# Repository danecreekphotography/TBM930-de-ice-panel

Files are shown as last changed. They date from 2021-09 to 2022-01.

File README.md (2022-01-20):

# TBM930 de-ice panel PCB

This PCB implements a TBM930 de-ice panel for use with Microsoft Flight Simulator
2020 and [MobiFlight](http://www.mobiflight.com/).



## KiBot automation

This repo also demonstrates using KiBot for full CI/CD of KiCad projects. Every pull request gets ERC/DRC checks.
Publishing a GitHub release triggers generation of a suite of PCB documentation, interactive BOM, and submission
files for JLCPCB (including pick-and-place files) and PCBWay. The GitHub release version is inserted into the
generated documentation and gerber files as well. A manually triggered workflow to generate documentation is also
included.

Want to use KiBot GitHub automation with your own project? Check out my [GitHub repository template](https://github.com/neilenns/KiBot-CICD-Template/) for KiCad CI/CD to get started!

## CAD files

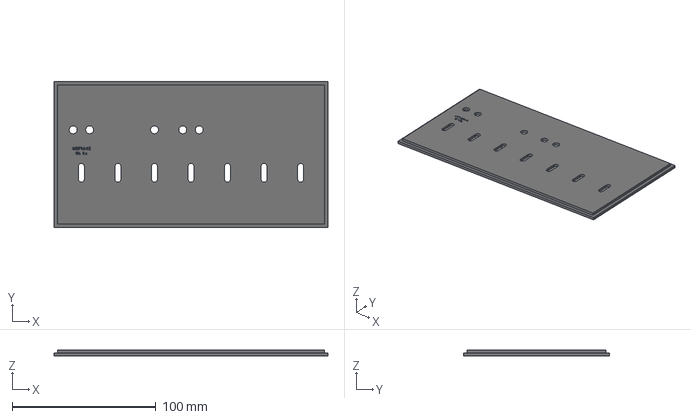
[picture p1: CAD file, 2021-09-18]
3d models/De-ice panel.step
190.5 x 101.6 x 4.00 mm

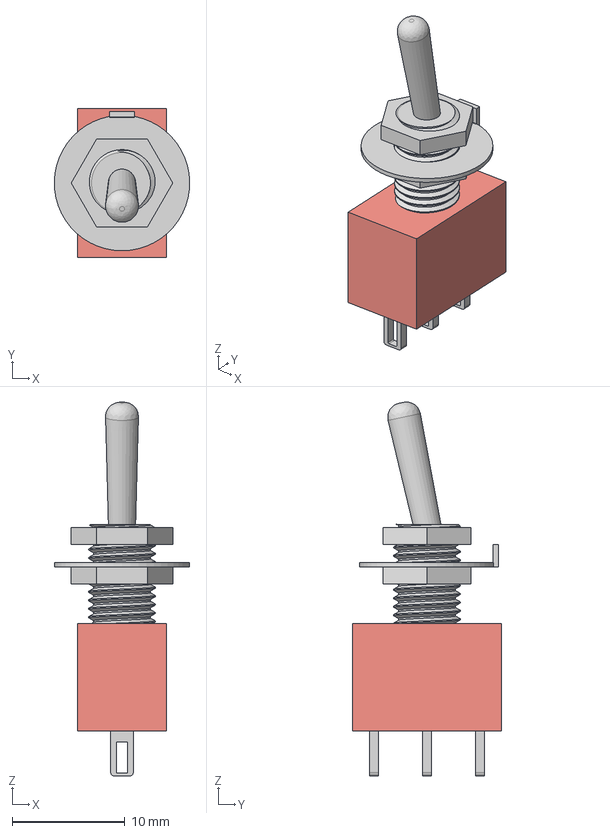
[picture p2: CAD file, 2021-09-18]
3d models/Mini toggle SPDT.step
12.0 x 13.2 x 33.1 mm
Switch body
Mounting screw
Nut x 2
Toggle

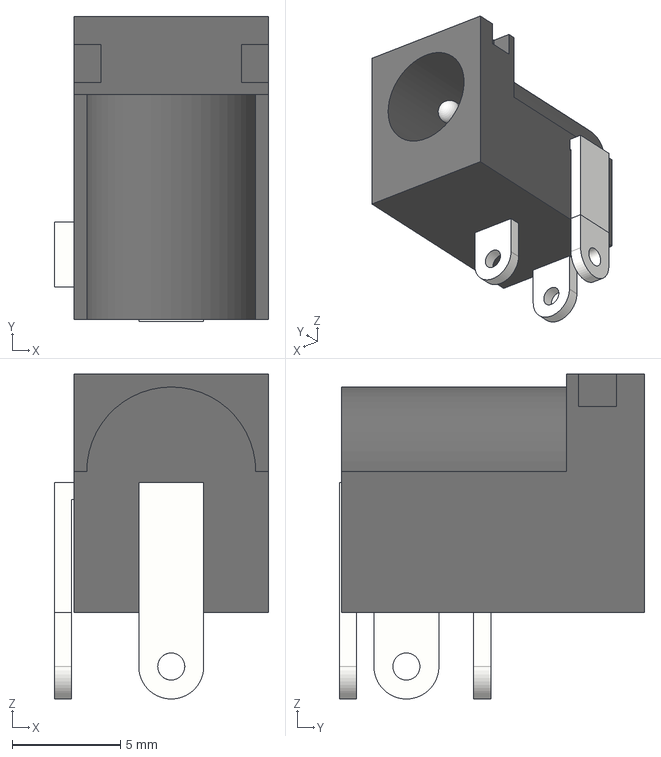
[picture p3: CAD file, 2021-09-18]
3d models/Barrel connector right angle.step
9.90 x 14.1 x 15.0 mm

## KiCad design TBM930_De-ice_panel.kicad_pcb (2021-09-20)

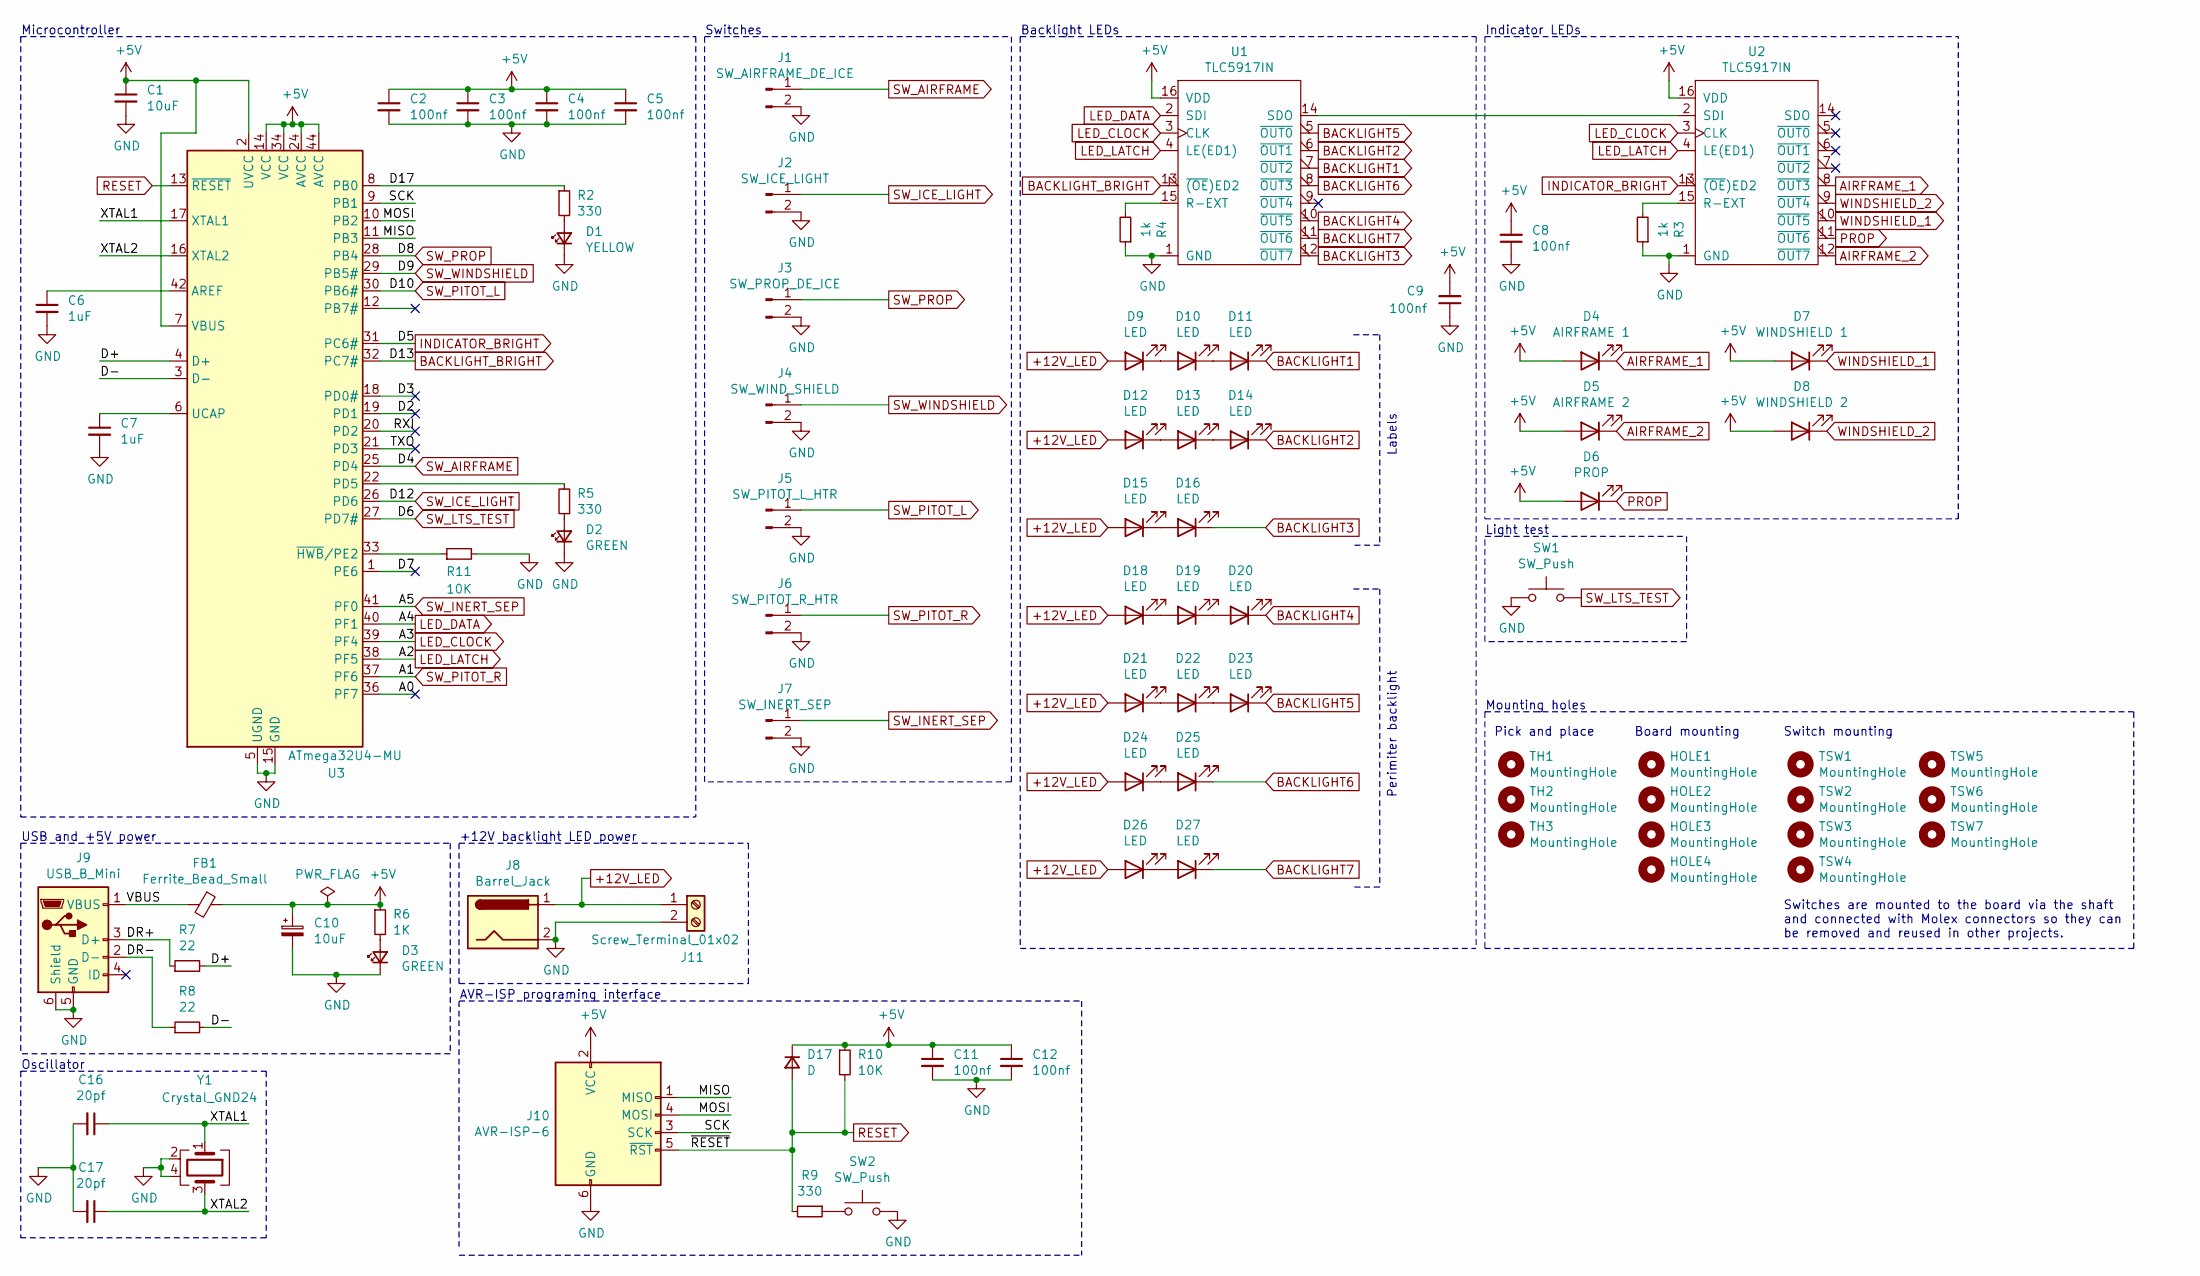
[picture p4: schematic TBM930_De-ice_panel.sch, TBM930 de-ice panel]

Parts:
C1, C10: 10uF; C_0603_1608Metric; JLC 0603
C2, C3, C4, C5, C8, C9, C11, C12: 100nf; C_0402_1005Metric; JLC 0402
C6, C7: 1uF; C_0402_1005Metric; JLC 0402
C16, C17: 20pf; C_0402_1005Metric; JLC 0402
D1: YELLOW; LED_0603_1608Metric; JLC LED_0603
D2, D3: GREEN; LED_0603_1608Metric; JLC LED_0603
D4: AIRFRAME 1; LED_D5.0mm
D5: AIRFRAME 2; LED_D5.0mm
D6: PROP; LED_D5.0mm
D7: WINDSHIELD 1; LED_D5.0mm
D8: WINDSHIELD 2; LED_D5.0mm
D9, D10, D11, D12, D13, D14, D15, D16, D18, D19, D20, D21, D22, D23, D24, D25, D26, D27: LED; LED_1206_3216Metric_Pad1.42x1.75mm_HandSolder
D17: D; D_SOD-323F; JLC SOD-323F
FB1: Ferrite_Bead_Small; C_0805_2012Metric; JLC 0805
HOLE1, HOLE2, HOLE3, HOLE4: MountingHole; MountingHole_3.2mm_M3
J1: SW_AIRFRAME_DE_ICE; Molex_KK-254_AE-6410-02A_1x02_P2.54mm_Vertical
J2: SW_ICE_LIGHT; Molex_KK-254_AE-6410-02A_1x02_P2.54mm_Vertical
J3: SW_PROP_DE_ICE; Molex_KK-254_AE-6410-02A_1x02_P2.54mm_Vertical
J4: SW_WIND_SHIELD; Molex_KK-254_AE-6410-02A_1x02_P2.54mm_Vertical
J5: SW_PITOT_L_HTR; Molex_KK-254_AE-6410-02A_1x02_P2.54mm_Vertical
J6: SW_PITOT_R_HTR; Molex_KK-254_AE-6410-02A_1x02_P2.54mm_Vertical
J7: SW_INERT_SEP; Molex_KK-254_AE-6410-02A_1x02_P2.54mm_Vertical
J8: Barrel_Jack; BarrelJack_Horizontal
J9: USB_B_Mini; USB_B_Mini_Amphenol_UE25BE5510H
J10: AVR-ISP-6; PinHeader_2x03_P2.54mm_Vertical
J11: Screw_Terminal_01x02; TerminalBlock_Phoenix_PT-1,5-2-5.0-H_1x02_P5.00mm_Horizontal
R2, R5, R9: 330; R_0402_1005Metric; JLC 0402
R3, R4: 1k; R_Axial_DIN0207_L6.3mm_D2.5mm_P7.62mm_Horizontal
R6: 1K; R_0402_1005Metric; JLC 0402
R7, R8: 22; R_0402_1005Metric; JLC 0402
R10, R11: 10K; R_0402_1005Metric; JLC 0402
SW1: SW_Push; SW_PUSH_6mm_H9.5mm
SW2: SW_Push; SW_PUSH_6mm_H4.3mm
TH1, TH2, TH3: MountingHole; JLCPCB_Tooling_Hole
TSW1, TSW2, TSW3, TSW4, TSW5, TSW6, TSW7: MountingHole; MiniToggleSPDT_screw_mount
U1, U2: TLC5917IN; DIP-16_W7.62mm
U3: ATmega32U4-MU; TQFP-44-1EP_10x10mm_P0.8mm_EP4.5x4.5mm
Y1: Crystal_GND24; Crystal_SMD_3225-4Pin_3.2x2.5mm; JLC SMD-CRY-3225_4P

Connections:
+5V: C1.1, C2.1, C3.1, C4.1, C5.1, C8.2, C9.2, C10.1, C11.1, C12.1, D4.2 (A), D5.2 (A), D6.2 (A), D7.2 (A), D8.2 (A), D17.1 (K), FB1.1, J10.2 (VCC), R6.1, R10.1, U1.16 (VDD), U2.16 (VDD), U3.2 (UVCC), U3.7 (VBUS), U3.14 (VCC), U3.24 (AVCC), U3.34 (VCC), U3.44 (AVCC)
+12V_LED: D9.2 (A), D12.2 (A), D15.2 (A), D18.2 (A), D21.2 (A), D24.2 (A), D26.2 (A), J8.1, J11.1
/A0: U3.36 (PF7)
/D2: U3.19 (PD1)
/D3: U3.18 (PD0#)
/D7: U3.1 (PE6)
/D17: R2.1, U3.8 (PB0)
/D+: R7.2, U3.4 (D+)
/D-: R8.2, U3.3 (D-)
/DR+: J9.3 (D+), R7.1
/DR-: J9.2 (D-), R8.1
/MISO: J10.1 (MISO), U3.11 (PB3)
/MOSI: J10.4 (MOSI), U3.10 (PB2)
/RXI: U3.20 (PD2)
/SCK: J10.3 (SCK), U3.9 (PB1)
/TXO: U3.21 (PD3)
/VBUS: FB1.2, J9.1 (VBUS)
/XTAL1: C16.1, U3.17 (XTAL1), Y1.1
/XTAL2: C17.1, U3.16 (XTAL2), Y1.3
AIRFRAME_1: D4.1 (K), U2.8 (~OUT3)
AIRFRAME_2: D5.1 (K), U2.12 (~OUT7)
BACKLIGHT1: D11.1 (K), U1.7 (~OUT2)
BACKLIGHT2: D14.1 (K), U1.6 (~OUT1)
BACKLIGHT3: D16.1 (K), U1.12 (~OUT7)
BACKLIGHT4: D20.1 (K), U1.10 (~OUT5)
BACKLIGHT5: D23.1 (K), U1.5 (~OUT0)
BACKLIGHT6: D25.1 (K), U1.8 (~OUT3)
BACKLIGHT7: D27.1 (K), U1.11 (~OUT6)
BACKLIGHT_BRIGHT: U1.13 (~(OE)ED2), U3.32 (PC7#)
GND: C1.2, C2.2, C3.2, C4.2, C5.2, C6.2, C7.2, C8.1, C9.1, C10.2, C11.2, C12.2, C16.2, C17.2, D1.1 (K), D2.1 (K), D3.1 (K), J1.2, J2.2, J3.2, J4.2, J5.2, J6.2, J7.2, J8.2, J9.5 (GND), J9.6 (Shield), J10.6 (GND), J11.2, R3.1, R4.1, R11.2, SW1.1, SW2.2, U1.1 (GND), U2.1 (GND), U3.5 (UGND), U3.15 (GND), U3.23 (GND), U3.35 (GND), U3.43 (GND), U3.45 (GND), Y1.2, Y1.4
INDICATOR_BRIGHT: U2.13 (~(OE)ED2), U3.31 (PC6#)
LED_CLOCK: U1.3 (CLK), U2.3 (CLK), U3.39 (PF4)
LED_DATA: U1.2 (SDI), U3.40 (PF1)
LED_LATCH: U1.4 (LE(ED1)), U2.4 (LE(ED1)), U3.38 (PF5)
unnamed: C6.1, U3.42 (AREF)
unnamed: C7.1, U3.6 (UCAP)
unnamed: D1.2 (A), R2.2
unnamed: D2.2 (A), R5.1
unnamed: D3.2 (A), R6.2
unnamed: D10.1 (K), D11.2 (A)
unnamed: D9.1 (K), D10.2 (A)
unnamed: D12.1 (K), D13.2 (A)
unnamed: D13.1 (K), D14.2 (A)
unnamed: D15.1 (K), D16.2 (A)
unnamed: D18.1 (K), D19.2 (A)
unnamed: D19.1 (K), D20.2 (A)
unnamed: D21.1 (K), D22.2 (A)
unnamed: D22.1 (K), D23.2 (A)
unnamed: D24.1 (K), D25.2 (A)
unnamed: D26.1 (K), D27.2 (A)
unnamed: R3.2, U2.15 (R-EXT)
unnamed: R4.2, U1.15 (R-EXT)
unnamed: R5.2, U3.22 (PD5)
unnamed: R9.1, SW2.1
unnamed: R11.1, U3.33 (~HWB~/PE2)
unnamed: U1.14 (SDO), U2.2 (SDI)
PROP: D6.1 (K), U2.11 (~OUT6)
RESET: D17.2 (A), J10.5 (~RST), R9.2, R10.2, U3.13 (~RESET)
SW_AIRFRAME: J1.1, U3.25 (PD4)
SW_ICE_LIGHT: J2.1, U3.26 (PD6)
SW_INERT_SEP: J7.1, U3.41 (PF0)
SW_LTS_TEST: SW1.2, U3.27 (PD7#)
SW_PITOT_L: J5.1, U3.30 (PB6#)
SW_PITOT_R: J6.1, U3.37 (PF6)
SW_PROP: J3.1, U3.28 (PB4)
SW_WINDSHIELD: J4.1, U3.29 (PB5#)
WINDSHIELD_1: D7.1 (K), U2.10 (~OUT5)
WINDSHIELD_2: D8.1 (K), U2.9 (~OUT4)

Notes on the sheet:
Switches
Switches are mounted to the board via the shaft and connected with Molex connectors so they can be removed and reused in other projects.
+12V backlight LED power
Backlight LEDs
USB and +5V power
Oscillator
Microcontroller
AVR-ISP programing interface
Labels
Perimiter backlight
Light test
Indicator LEDs
Pick and place
Board mounting
Switch mounting
Mounting holes

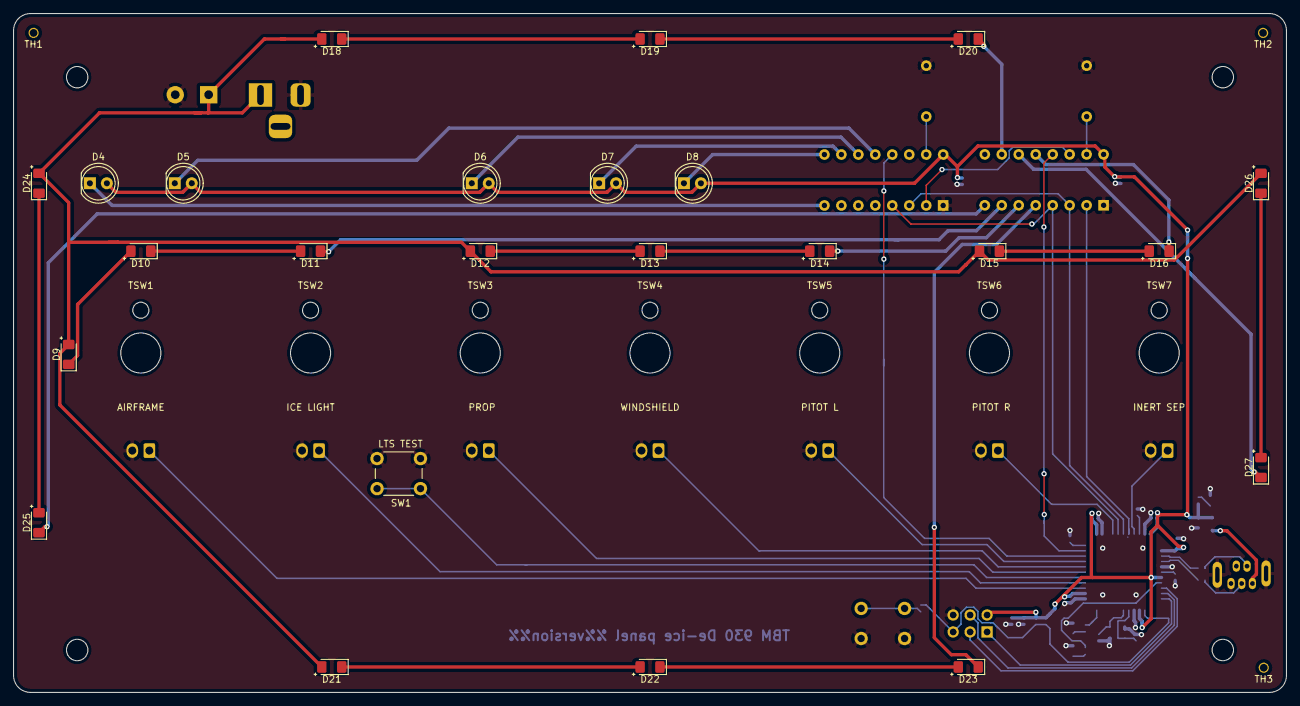
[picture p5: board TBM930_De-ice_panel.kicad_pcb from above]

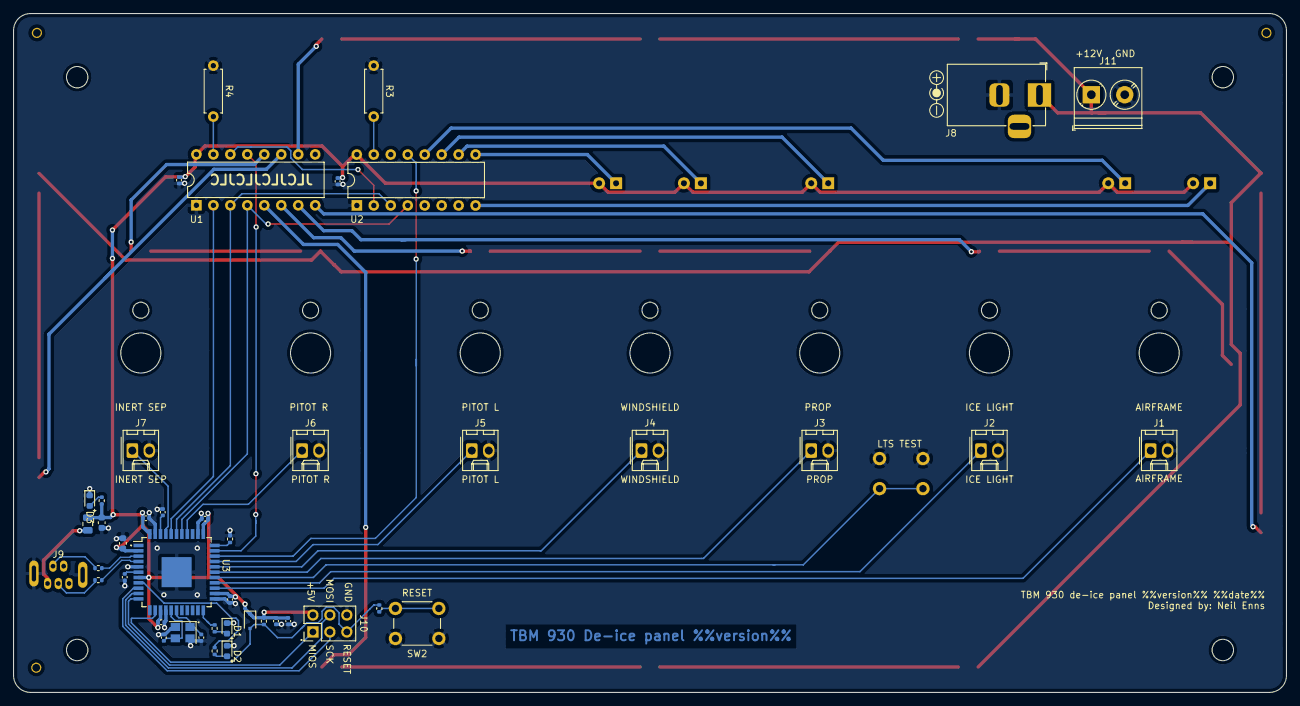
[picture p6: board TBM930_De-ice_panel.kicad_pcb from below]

Board: 2 copper layers, 190.5 x 101.6 mm, 83 parts (45 on the bottom side), 62 nets.

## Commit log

2021-09-18 Initial version (#1)
    * Initial version
    * Fix descriptions and paths
    * Fix descriptions and paths
    * Add pull request to release.yml for testing
    * Trying again to trigger on pull request
    * Fix job name
    * Trying substitution again
    * Remove single quote
    * Try and fix folder structure
    * Trying again to exclude files
    * Trying wildcard change to flatten folder
    * Trying again to flatten folder structure
    * Gonna try doing a release!
    [Barrel connector right angle.step, De-ice panel.step, Mini toggle SPDT.step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]
2021-09-18 Switch to env variables, zip the release (#3)
2021-09-19 Fix missing BOM files
2021-09-19 Set version in PCB as well
    [TBM930_De-ice_panel.kicad_pcb]
2021-09-19 Fix typo in JLC BOM zip
2021-09-19 Fix switches back to ground connection (#4)
    [TBM930_De-ice_panel.kicad_pcb, TBM930_De-ice_panel.sch]
2021-09-19 Add PCBWay, clean up some names
2021-09-19 Fix case of filename
2021-09-19 Fix PCBWay upload, add MobiFlight config
2021-09-20 Fix output name for white PCB renders
2021-09-20 Test date output (#5)
    * Test date output
    * Try again
    * Change time format
    * Renaming for clarity
    * Try setting the timezone
    * Test timezone again
    * Add date test to preflight
    * Trying again
    * Add quotes
    * Fix timezone name
    * Update schematic and PCB to use date
    * Update build and release to replace date
    [TBM930_De-ice_panel.kicad_pcb, TBM930_De-ice_panel.sch]
2021-09-20 Date stamp (#6)
    * Remove extra quotes
    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
2021-09-20 Fix date placeholder on PCB
    [TBM930_De-ice_panel.kicad_pcb]
2021-09-20 Test a subsheet
    [TBM930_De-ice_panel.sch, Test subsheet.sch]
2021-09-20 Test a subsheet (#11)
    [TBM930_De-ice_panel.sch, Test subsheet.sch]
2021-09-21 Upload artifacts (#13)
    * Upload artifacts
    * Remove subsheet
    * Remove subsheet
    [TBM930_De-ice_panel.sch, Test subsheet.sch]
2021-09-29 Remove incorrect filter
2021-10-01 Remove stray env variable for version that doesn't apply to this flow
2021-10-07 Add photo of completed PCB
2022-01-20 Add MF board configuration file

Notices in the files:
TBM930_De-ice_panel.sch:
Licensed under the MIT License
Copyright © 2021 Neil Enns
